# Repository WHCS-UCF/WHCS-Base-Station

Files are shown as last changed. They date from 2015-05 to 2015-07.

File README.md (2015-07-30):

# WHCS Base Station Design

The KiCad source files for WHCS' base station board.
The published rev 1.0 board is available on [OSHPark](https://oshpark.com/shared_projects/1ZnSgowG).

## Requirements
KiCad 2013-05-18 and some extra libraries

## Board Front
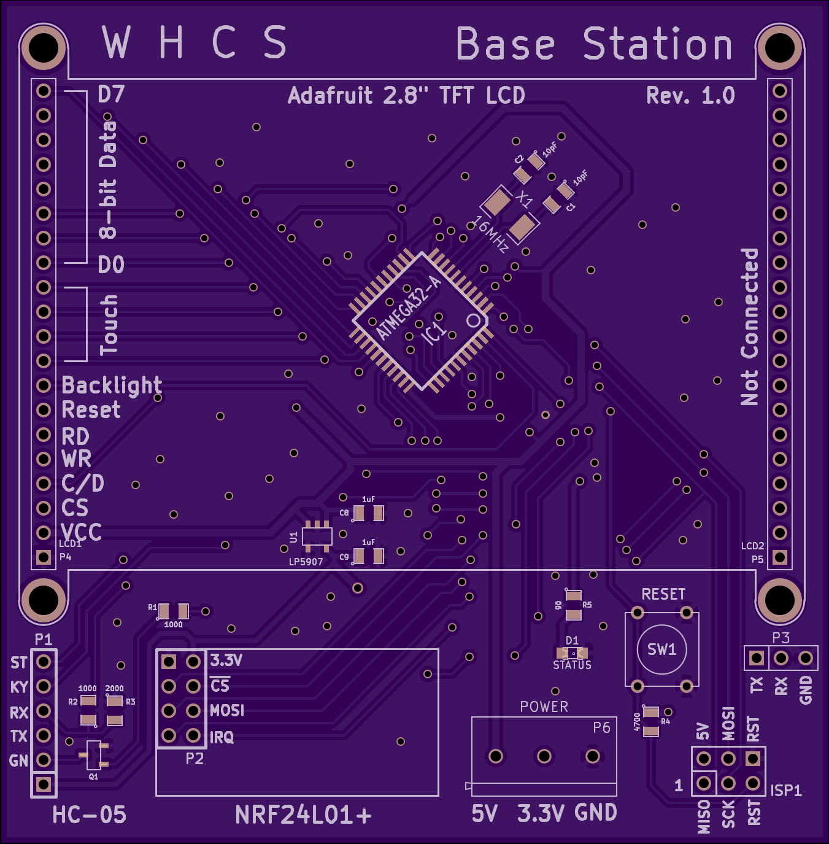
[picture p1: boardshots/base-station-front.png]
Board Front


## Board Back
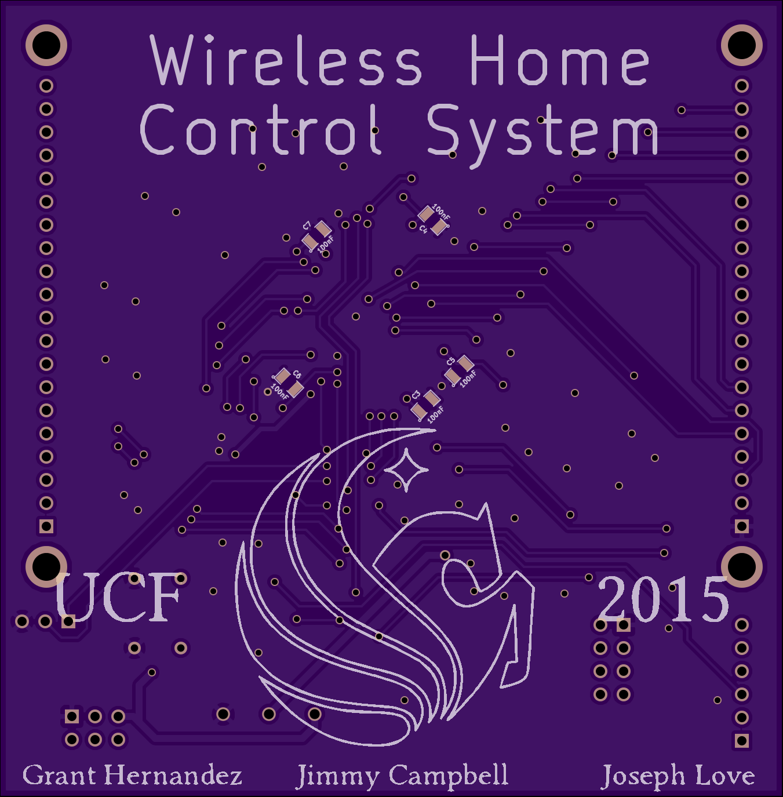
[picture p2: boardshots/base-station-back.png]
Board Back


### Author
Grant Hernandez<br/>
*Computer Engineer*

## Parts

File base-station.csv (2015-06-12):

Component | Value | Footprint | Header Type
C1 | 10pF | SM0805
C2 | 10pF | SM0805
C3 | 100nF | SM0805
C4 | 100nF | SM0805
C5 | 100nF | SM0805
C6 | 100nF | SM0805
C7 | 100nF | SM0805
C8 | 1uF | SM0805
C9 | 1uF | SM0805
CON1 | ISP | pin_array_3x2 | Male
D1 | STATUS | LED-0805
IC1 | ATMEGA32-A | TQFP44
P1 | HC-05 | PIN_ARRAY-6X1 | Female
P2 | NRF24L01+ | pin_array_4x2 | Female
P3 | SERIAL | PIN_ARRAY_3X1 | Male
P4 | LCD1 | PIN_ARRAY_20X1
P5 | LCD2 | PIN_ARRAY_20X1 | Female
P6 | POWER | terminal-282836-3 | Female
Q1 | BTEN | SOT23
R1 | 1000 | SM0805
R2 | 1000 | SM0805
R3 | 2000 | SM0805
R4 | 4700 | SM0805
R5 | 90 | SM0805
SW1 | RESET | SW_PUSH_SMALL
U1 | LP5907 | SOT23-5
X1 | 16MHz | 2-SMD

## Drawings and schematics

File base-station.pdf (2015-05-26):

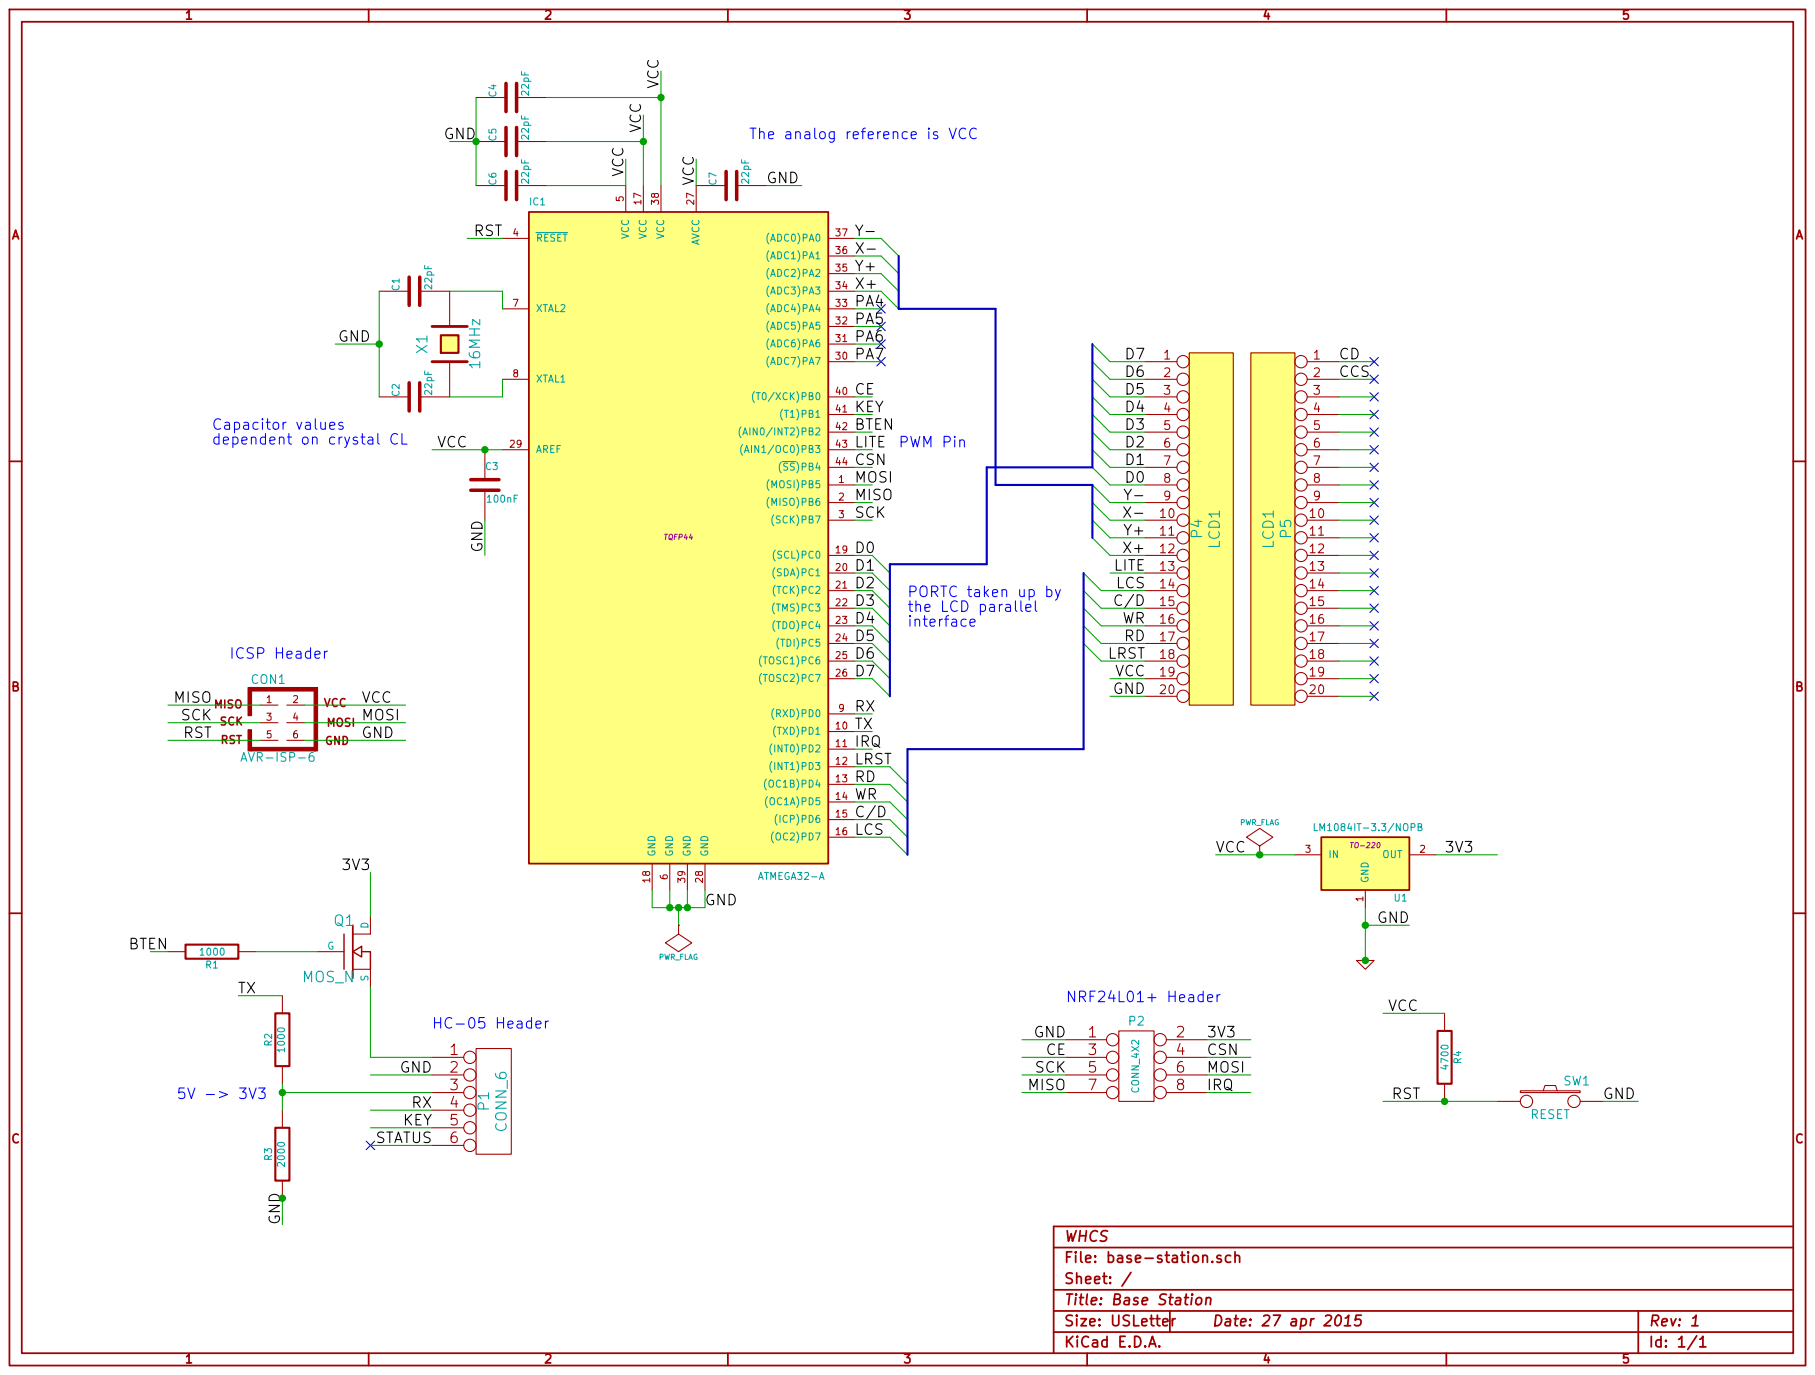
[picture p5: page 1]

The analog reference is VCC

WHCS
Title: Base Station File: base-station.sch Sheet: /

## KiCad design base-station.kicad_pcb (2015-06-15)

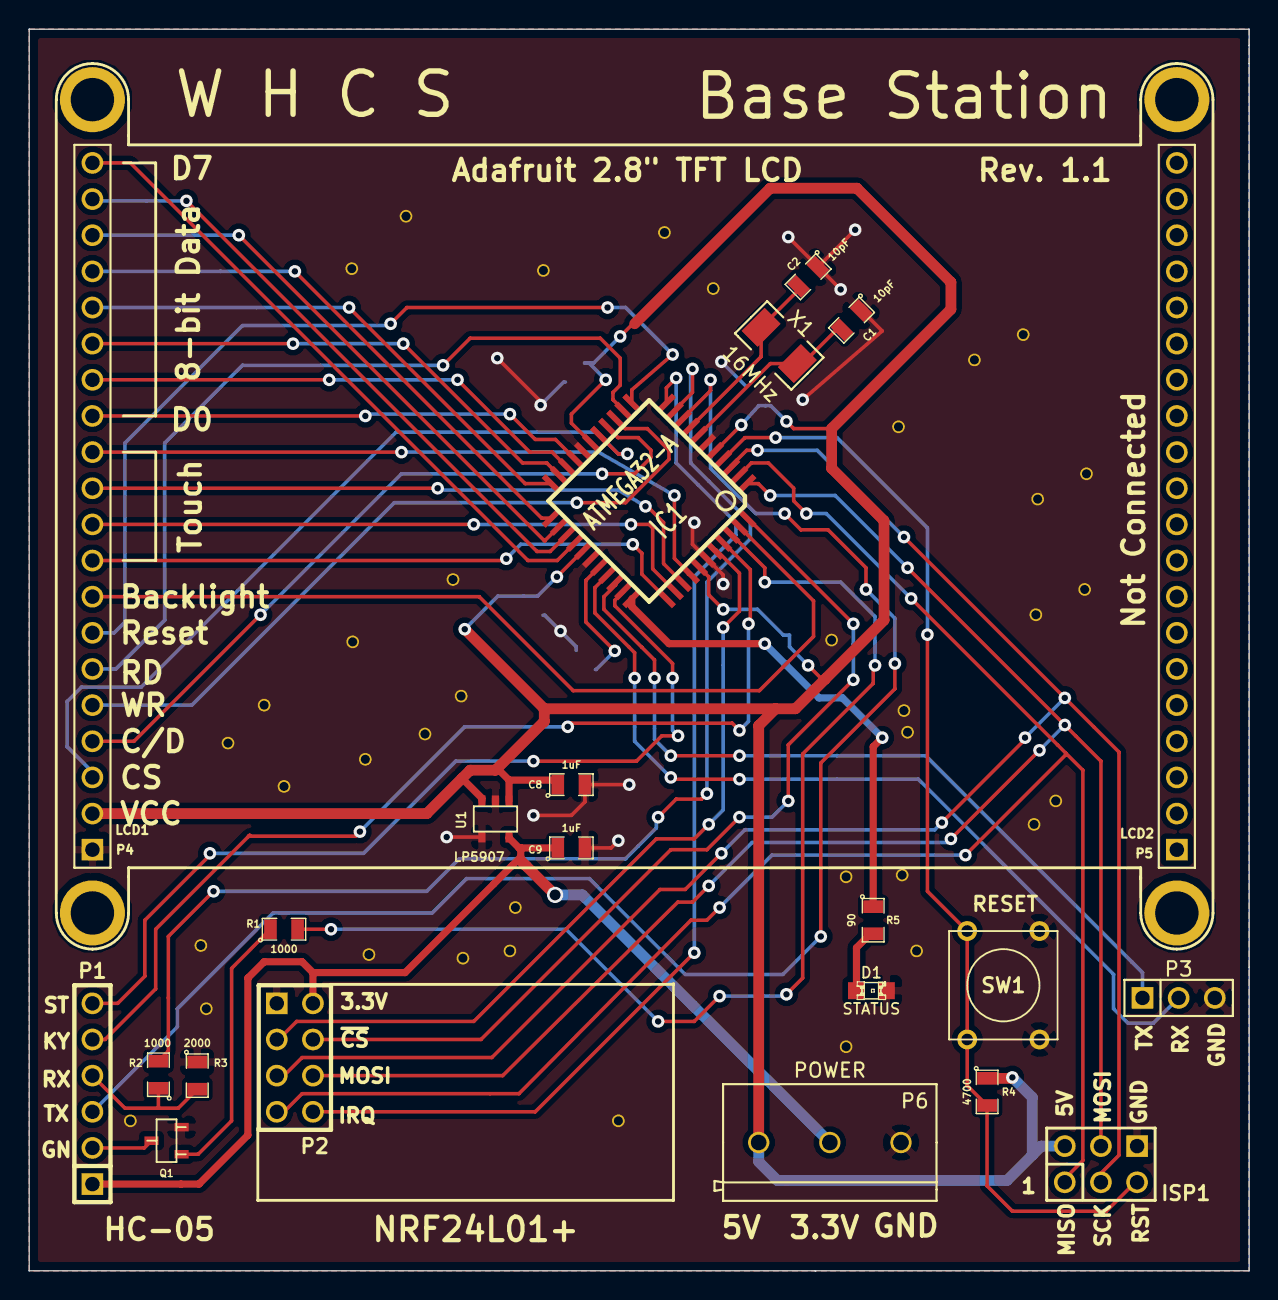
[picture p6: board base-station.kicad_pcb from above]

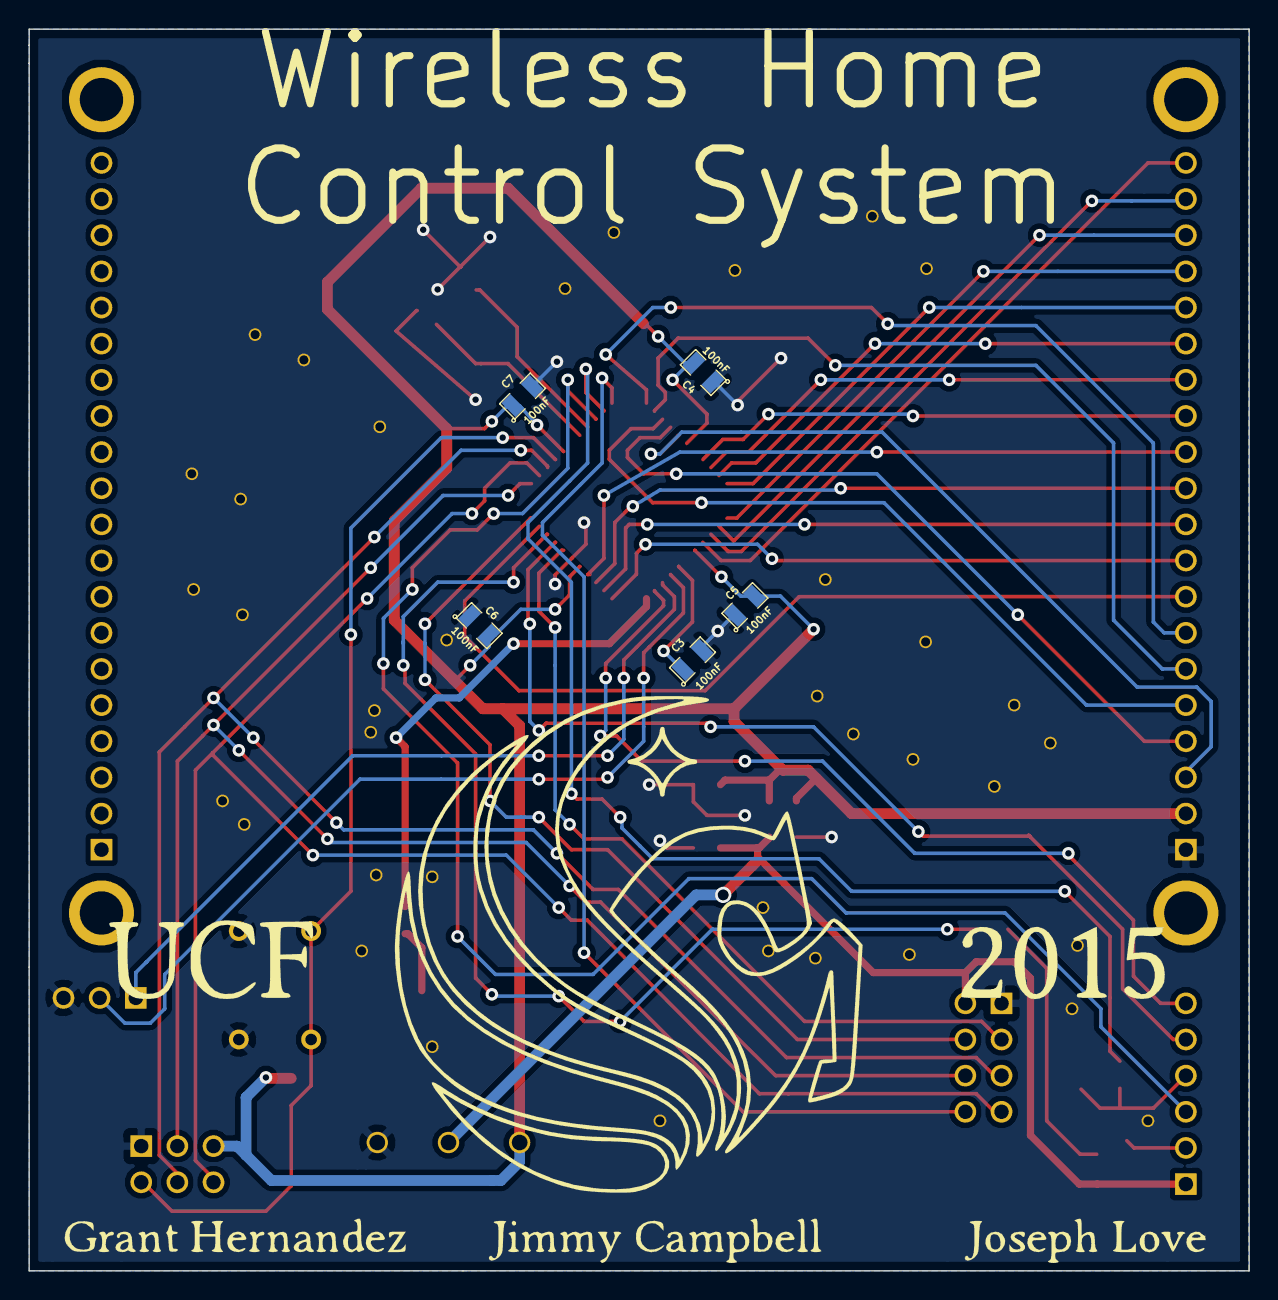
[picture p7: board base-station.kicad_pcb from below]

Board: 2 copper layers, 85.7 x 87.2 mm, 27 parts (5 on the bottom side), 43 nets.

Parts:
C1, C2: 10pF; SM0805
C3, C4, C5, C6, C7: 100nF; SM0805
C8, C9: 1uF; SM0805
D1: STATUS; LED-0805
IC1: ATMEGA32-A; TQFP44
ISP1: ISP; pin_array_3x2
P1: HC-05; PIN_ARRAY-6X1
P2: NRF24L01+; pin_array_4x2
P3: SERIAL; PIN_ARRAY_3X1
P4: LCD1; PIN_ARRAY_20X1
P5: LCD2; PIN_ARRAY_20X1
P6: POWER; terminal-282836-3
Q1: BTEN; sot23
R1, R2: 1000; SM0805
R3: 2000; SM0805
R4: 4700; SM0805
R5: 90; SM0805
SW1: RESET; SW_PUSH_SMALL
U1: LP5907; SOT23-5
X1: 16MHz; 2-SMD

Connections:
/3V3: C9.1, P1.1, P2.2, P6.2, U1.5
/BTEN: IC1.42, R1.2
/CD: IC1.15, P4.4
/CE: IC1.40, P2.3
/CSN: IC1.44, P2.4
/D0: IC1.19, P4.13
/D1: IC1.20, P4.14
/D2: IC1.21, P4.15
/D3: IC1.22, P4.16
/D4: IC1.23, P4.17
/D5: IC1.24, P4.18
/D6: IC1.25, P4.19
/D7: IC1.26, P4.20
/HC_GND: P1.2, Q1.2
/IRQ: IC1.11, P2.8
/KEY: IC1.41, P1.5
/LCS: IC1.16, P4.3
/LITE: IC1.43, P4.8
/LRST: IC1.12, P4.7
/MISO: IC1.2, ISP1.1, P2.7
/MOSI: IC1.1, ISP1.4, P2.6
/PA4: IC1.33, R5.1
/RD: IC1.13, P4.6
/RST: IC1.4, ISP1.5, R4.2, SW1.1
/RX: IC1.9, P1.3
/RX_SOFT: IC1.30, P3.2
/SCK: IC1.3, ISP1.3, P2.5
/STATUS: IC1.32, P1.6
/TX: IC1.10, R2.2
/TX_SOFT: IC1.31, P3.1
/VCC: C4.2, C5.2, C6.2, C7.1, C8.1, IC1.5, IC1.17, IC1.27, IC1.38, ISP1.2, P4.2, P6.1, R4.1, U1.1, U1.3
/WR: IC1.14, P4.5
/X+: IC1.34, P4.9
/X-: IC1.36, P4.11
/Y+: IC1.35, P4.10
/Y-: IC1.37, P4.12
GND: C1.1, C2.1, C3.2, C4.1, C5.1, C6.1, C7.2, C8.2, C9.2, D1.2, IC1.6, IC1.18, IC1.28, IC1.39, ISP1.6, P2.1, P3.3, P4.1, P6.3, Q1.3, R3.1, SW1.2, U1.2, U1.4
unnamed: C1.2, IC1.7, X1.2
unnamed: C2.2, IC1.8, X1.1
unnamed: Q1.1, R1.1
unnamed: P1.4, R2.1, R3.2
unnamed: D1.1, R5.2
unnamed: C3.1, IC1.29

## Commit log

2015-05-26 Initial commit for the WHCS base station
    [base-station.sch]
2015-06-12 Board revision 1.0
    [base-station.csv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]
2015-06-13 Minor power track edits
    [base-station.kicad_pcb]
2015-06-13 Fix LCD and HC-05 wiring mixups. Improved pours
    [base-station.kicad_pcb, base-station.sch]
2015-06-14 More ground pour vias. Silk screen adjustments
    [base-station.kicad_pcb]
2015-06-14 Moved HC-05 NMOS to low-side
    [base-station.kicad_pcb, base-station.sch]
2015-06-14 Minor silk screen adjustments for the LCD
    [base-station.kicad_pcb]
2015-06-15 Added UCF logo
    [base-station.kicad_pcb]
2015-06-15 Lower LCD support drill clearances to 0.02in
    [base-station.kicad_pcb]
2015-06-15 Add Wireless Home Control System text to B.SilkS
    [base-station.kicad_pcb]
2015-06-15 OSHPark Submit
    [base-station-B_Cu.gbl, base-station-B_Mask.gbs, base-station-B_SilkS.gbo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]
2015-06-15 Adjust Via drill size (seen from OSHPark picture)
    [base-station.kicad_pcb]
2015-06-15 Fix ISP SilkS bug and revision bump
    [base-station.kicad_pcb]
2015-07-30 Add boardshots for rev 1.0
